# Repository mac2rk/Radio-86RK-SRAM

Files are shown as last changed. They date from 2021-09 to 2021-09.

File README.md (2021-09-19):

# Radio-86RK SRAM
The 2012 remake of the 1986 DIY 8-bit computer

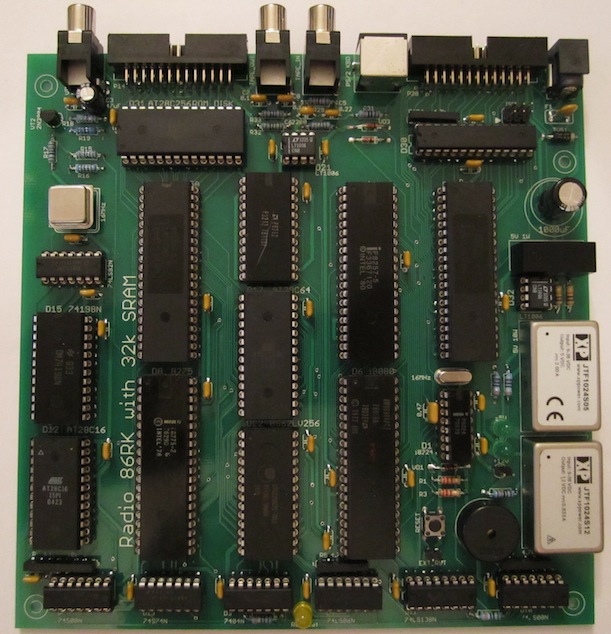
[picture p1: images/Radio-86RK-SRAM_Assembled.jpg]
Radio 86RK SRAM


## Contents
* [Introduction](#introduction)
* [Specifications](#specifications)
* [Hardware documentation](#hardware-documentation)
  * [Schematic and PCB Layout](#schematic-and-pcb-layout)
  * [Connectors](#connectors)
  * [Bill of Materials](#bill-of-materials)
  * [Memory Map](#memory-map)
* [Firmware documentation](#firmware-documentation)
  * [Monitor](#monitor)
  * [PS/2 adapter](#ps2-adapter)
* [Known Issues](#known-issues)

## Introduction
This project is a 2012 remake of [Radio-86RK](https://en.wikipedia.org/wiki/Radio-86RK), a DIY 8-bit computer the original design for which was published in 1986 by the Soviet *Radio* ham and DIY electronics magazine (hence the "Radio" and "86" in the name).

The original 1986 design targeted an enthusiast building it from scratch and was notable for its relative simplicity. Like most home computers of the era, it uses TV for video output and a cassette tape for program storage. Unlike most home computers, there is no color and no bitmapped graphics. You can get a feel of it via @begoon's excellent online [emulator](https://rk86.ru/) (the emulator's source code is [available on GitHub](https://github.com/begoon/rk86-js)).

The principal motivation behind this project was to replace the obsolete 1-bit DRAM memory and its supporting logic (address multiplexers, etc.) with a single 32KiB static RAM chip. A number of other changes has been made - see the [schematic](Eagle/Radio-86RK-SRAM-Schematic.pdf) for details. The project was initially [published](http://radio86rk.pbworks.com) around 2012 and since then has been built by a number of people, with one build even landing at the [Center for Computing History](http://www.computinghistory.org.uk/det/32376/Radio-86RK-(Russia)/) in Cambridge, thanks to @begoon. Also, this project seems to have inspired other designs, particularly @skiselev's [Radio-86RK](https://github.com/skiselev/radio-86rk) and [Радио-86РК-SRAM-128K](http://www.nedopc.org/forum/viewtopic.php?t=10660&start=0) by @shaos. 

## Specifications
  * CPU: Intel i8080 @ 2MHz
  * Memory: 32KiB RAM, 8 KiB ROM, optional 32KiB ROM cartridge (built-in or external)
  * Display: 64x25 alphanumeric monochrome (50Hz composite video output suitable for TV)
  * Keyboard: Proprietary 66-key (parallel interface) or any standard PS/2 (with built-in adapter)
  * Sound: 1-bit digital
  * I/O: Cassette tape recorder (use [mac2rk](https://github.com/mac2rk/mac2rk) to emulate tape recorder with a sound card)
  * Expansion: optional parallel port (required for ROM cartridges) 
  * Software: 2KiB ROM monitor; additional software can be loaded from a ROM cartridge or tape
  * Form factor: Mini-ITX (170x170 mm, 6.7x6.7 inch)
  * Power supply: 18-36VDC @ approx. 5W via barrel connector

## Hardware documentation

### Schematic and PCB Layout
[Schematic](Eagle/Radio-86RK-SRAM-Schematic.pdf)
[PCB Layout](Eagle/Radio-86RK-SRAM-Silk.pdf)

The computer is built around an Intel i8080 CPU (D6 on the schematic) with i8224 clock generator (D1). RAM and ROM are implemented with 62256 SRAM (D22) and 28C64 EEPROM (D17), respectively. Video subsystem includes an i8275 CRT controller (D8), i8257 DMA controller (D2) with address latch (D7), 28C16 font EEPROM (D12) and a parallel-in, serial-out shift register (D15). Two i8255 Programmable Peripheral Interfaces (PPIs) provide I/O connectivity. One PPI (D20) interfaces a cassete tape recorder and the parallel keyboard; a PS/2 keyboard can be connected via an onboard adapter (D30). The second PPI (D14) implements the expansion port, which can be used, among other things, to connect ROM cartridges. A 28C256 ROM cartridge can be either installed onboard (D30) or connected via a 26-way expansion header. The onboard power supply with power sequencing is built with three DC/DC converter modules (D33..D35) and an opamp (D32).

### Connectors
[Connectors](docs/Connectors.md)

### Bill of Materials
[Bill of Materials](docs/BOM.md)

### Memory Map
[Memory Map](docs/Memory_map.md)

## Firmware Documentation

### Monitor

[Monitor commands and subroutines](docs/Monitor.md)

### PS/2 adapter
The PS/2 to parallel keyboard adapter based on an ATmega48/88/168/328 MCU was developed and [published](https://zx-pk.ru/threads/9294-orion-128-kontroller-ps-2-klaviatury.html) by Kamil Karimov (caro). The source code for the adapter is not available, but the binary is known to work. Note that this adapter requires that the keyboard support Scan Code Set 3. Most do, but some (e.g. Logitech K100) don't and will not work properly with the adapter.

There are two separate versions of the compiled binary: one for ATmega48/88 and one for ATmega168/328. When programming the ATmega, all fuses except CKDIV8 should be left in their default states. CKDIV8 should be left unprogrammed. (CKDIV8 is programmed by default, which clocks the ATmega at 1MHz. With this clock, only Caps Lock (= Rus/Lat) and Print Screen (= Reset) will work normally. Other keys will not work at all or will work partially or intermittently.)

## Known Issues

* Top silkscreen: R109, which sets the current for the "+12V" LED, has a wrong value. Instead oof 330 ohm, it should be between 1kOhm and 1.5kOhm
* PS/2 adapter requires that the keyboard support Scan Code Set 3. Most do, but some (e.g. Logitech K100) don't and do not work properly with the adapter.

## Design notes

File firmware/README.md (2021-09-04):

# Radio-86RK SRAM firmware

radio86rk-monitor.bin - Monitor (28C64)
radio86rk-font.bin    - Font    (28C16)

## PS/2 Keyboard Adapter for Radio-86RK and similar computers with ATMega48(/88/168)

orion_kb_m48.hex - for ATmega48/88
orion_kb_m168.hex - for ATmega168/328

### PS/2 Keyboard Layouts

PS/2 adapter firmware implements two alternative keyboard layouts for convenience when working with both Latin and Cyrillic, which use different layouts on RK86 from compared to PC. With two layouts, you will see on the screen what is on the key.

Scroll Lock key will switch between two layouts. Scroll Lock indicator will show what layout is active. What Scroll Lock is off, the layout is Latin (QWERTY), when on - Cyrillic.

### Radio-86RK matrix layout

 A   | D7 | D6 | D5 | D4 | D3 | D2 | D1 | D0
 --- | ---- | ---- | ---- | ---- | ---- | ---- | ---- | ---
 A7 | SP | ^  | ]  | \  | [  | Z  | Y  | X
 A6 | W  | V  | U  | T  | S  | R  | Q  | P
 A5 | O  | N  | M  | L  | K  | J  | I  | H
 A4 | G  | F  | E  | D  | C  | B  | A  | @
 A3 | /  | .  | =  | ,  | ;  | :  | 9  | 8
 A2 | 7  | 6  | 5  | 4  | 3  | 2  | 1  | 0
 A1 | v  | -> |  ^ | <- | BS | CR | LF | TAB
 A0 | F5 | F4 | F3 | F2 | F1 | ESC | CLR | ^\

### Programming ATMega48 with PS/2 adapter firmware

The default Fuse and Lock bits for an ATmega48 are as follows:

Lock(&Fuse) | Fuse(Low)  | Fuse(High)    | Fuse(Ext)
------------ | ------------ | --------------- | ------------------
[v] LB1     | [ ] CKSEL0 | [v] BODLEVEL0 | [v] SELFPRGEN
[v] LB2     | [v] CKSEL1 | [v] BODLEVEL1 | [v] -
[v] BLB01   | [ ] CKSEL2 | [v] BODLEVEL2 | [v] -
[v] BLB10   | [ ] CKSEL3 | [v] EESAVE    | [v] -
[v] BLB11   | [ ] SUT0   | [v] WDTON     | [v] -
[v] BLB12   | [v] SUT1   | [ ] SPIEN     | [v] -
[v] -       | [v] CKOUT  | [v] DWEN      | [v] -
[v] -       | [ ] CKDIV8 | [v] RSTDISBL  | [v] -

You need to change:
1) Fuse(Low)/CKDIV8
2) Fuse(High)/BODLEVEL0,1

The result should look like:

Lock(&Fuse) | Fuse(Low)  | Fuse(High)    | Fuse(Ext)
------------ | ------------ | --------------- | ------------------
[v] LB1     | [ ] CKSEL0 | [ ] BODLEVEL0 | [v] SELFPRGEN
[v] LB2     | [v] CKSEL1 | [ ] BODLEVEL1 | [v] -
[v] BLB01   | [ ] CKSEL2 | [v] BODLEVEL2 | [v] -
[v] BLB10   | [ ] CKSEL3 | [v] EESAVE    | [v] -
[v] BLB11   | [ ] SUT0   | [v] WDTON     | [v] -
[v] BLB12   | [v] SUT1   | [ ] SPIEN     | [v] -
[v] -       | [v] CKOUT  | [v] DWEN      | [v] -
[v] -       | [V] CKDIV8 | [v] RSTDISBL  | [v] -

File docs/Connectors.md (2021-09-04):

# Radio-86RK SRAM Connectors
## VIDEO_OUT - Composite Video (RCA connector)

Pin | Description     
--- | ---------------
Tip (the inner contact) | Output: Composite Video
Ring / Sleeve |	Power: GND

## P14 - Expansion Port Connector (26-way box header)
Do not use if the internal ROM cartridge (D31) is installed.

Pin | Description | Pin | Description
--- | ----------- | --- | ----------------
1   | I/O: PC0 | 2   | I/O: PA0
3   | I/O: PC1 | 4   | I/O: PA1
5   | I/O: PC2 | 6   | I/O: PA2
7   | I/O: PC3 | 8   | I/O: PA3
9   | I/O: PC4 | 10  | I/O: PA4
11  | I/O: PC5 | 12  | I/O: PA5
13  | I/O: PC6 | 14  | I/O: PA6
15  | I/O: PC7 | 16  | I/O: PA7
17  | I/O: PB7 | 18  | I/O: PB0
19  | I/O: PB6 | 20  | I/O: PB1
21  | I/O: PB5 | 22  | I/O: PB2
23  | I/O: PB4 | 24  | I/O: PB3
25  | Power: +5V  | 26  | Power: GND

## TAPE_OUT - Tape Recorder Output (RCA connector)

Pin | Description     
--- | ---------------
Tip (the inner contact) | Output: Tape Recorder
Ring / Sleeve |	Power: GND

## TAPE_IN - Tape Recorder Input (RCA connector)

Pin | Description     
--- | ---------------
Tip (the inner contact) | Input: Tape Recorder
Ring / Sleeve |	Power: GND

## PS/2_KBD - PS/2 Keyboard (6-way Mini DIN)

Pin | Description     
--- | ---------------
1   | Input/Output: Data
2   |	Not connected
3   |	Power: GND
4   |	Power: +5V
5   |	Input/Output: Clock
6   |	Not connected

## P20 - Parallel Keyboard Connector (26-way box header)
Do not use if PS/2 adapter (D30) is installed.

Pin | Description | Pin | Description
--- | ----------- | --- | ----------------
1   | I/O: PC0 | 2   | I/O: PA0
3   | I/O: PC1 | 4   | I/O: PA1
5   | I/O: PC2 | 6   | I/O: PA2
7   | I/O: PC3 | 8   | I/O: PA3
9   | I/O: PC4 | 10  | I/O: PA4
11  | I/O: PC5 | 12  | I/O: PA5
13  | I/O: PC6 | 14  | I/O: PA6
15  | I/O: PC7 | 16  | I/O: PA7
17  | I/O: PB7 | 18  | I/O: PB0
19  | I/O: PB6 | 20  | I/O: PB1
21  | I/O: PB5 | 22  | I/O: PB2
23  | I/O: PB4 | 24  | I/O: PB3
25  | Power: +5V  | 26  | Power: GND

## ISP - In-System Programming for PS/2 Adapter

Pin | Description     
--- | ---------------
1   | Output: Data
2   |	Power: +5V
3   |	Input: Clock
4   |	Input: Data
5   |	Input: Reset (active low)
6   |	Power: GND

## 24V_IN - Power (18..36VDC @ 5W)

Pin | Description     
--- | ---------------
Tip (the inner contact) | Power: 18..36V (positive terminal)
Barrel / Sleeve         |	Power: GND (negative terminal)

## EXT_RST - Reset

Pin | Description     
--- | ---------------
1   | Input: Reset (active low)
2   |	Power: GND

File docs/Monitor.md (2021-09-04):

# Radio-86RK SRAM Monitor
(based on @skiselev's work)

## Monitor Commands
* **D\<Start_Address\>,\<End_Address\>** - Display memory content in hexadecimal
* **L\<Start_Address\>,\<End_Address\>** - Display memory content in ASCII
* **F\<Start_Address\>,\<End_Address\>,\<Value\>** - Fill memory with the specified value
* **M\<Address\>** - Modify memory content
* **T\<Start_Address\>,\<End_Address\>,\<Destination_Start_Address\>** - Copy memory block to destination
* **C\<Start_Address\>,\<End_Address\>,\<Destination_Start_Address\>** - Compare memory block with destination
* **S\<Start_Address\>,\<End_Address\>,\<Value\>** - Search memory for a value
* **R\<ROM_Start_Address\>,\<ROM_End_Address\>,\<Destination_Start_Address\>** - Read from the ROM cartridge
* **G\<Start_Address\>\[,End_Address\]** - Run code, optionally stop at the specified address
* **X** - Display and modify registers
* **O\<Start_Address\>,\<End_Address\>\[,Speed\]** - Write memory to cassette. Default speed is 1Dh / 1200 bps
* **I\[Offset\]\[,Speed\]** - Read data from to cassette memory at specified offset

## Monitor Subroutines:
* 0F803h - Keyboard input
  * Input: None
  * Output: A - character code read from keyboard
* 0F806h - Cassette input
  * Input: A=0FFh - with sync; A=08h - no sync
  * Output: A - data read from cassette
* 0F809h - Print character to screen
  * Input: C - character to print
* 0F80Ch - Cassette output
  * Input: C - data to write
* 0F812h - Query keyboard
  * Output: A=00h - key not pressed; A=0FFh - key pressed
* 0F815h - Print to screen in hex
  * Input: A - data to print
* 0F818h - Print string
  * Input: HL - string address
* 0F81Bh - Get key
  * Output: A=0FFh - key not pressed; A=0FEh - Rus/Lat; otherwise A - key code
* 0F81Eh - Get cursor position
  * Output: H - row, L - column
* 0F821h - Read character from screen at current cursor position
  * Output: A - char read from screen
* 0F824h - Read from cassette
  * Input: HL - offset of memory buffer to store data to
  * Output: HL - start; DE - end; BC - checksum

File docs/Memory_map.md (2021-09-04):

# Radio-86RK SRAM Memory Map
* 0000h - 7FFFh - SRAM
  * 7600h - 7FFFh - Display buffer and monitor variables
* 8000h - 8FFFh - 8255A PPI (D20 - Keyboard and Cassette Tape Recorder)
  * 8000h - Channel A data
  * 8001h - Channel B data
  * 8002h - Channel C data
  * 8003h - Control word
* 9000h - 9FFFh - Unused
* 0A000h - 0AFFFh - 8255A PPI (D14 - Expansion Port)
  * 0A000h - Channel A data
  * 0A001h - Channel B data
  * 0A002h - Channel C data
  * 0A003h - Control word
* 0B000h - 0BFFFh - Unused
* 0C000h - 0CFFFh - 8275 CRT Controller
* 0D000h - 0DFFFh - Unused
* 0E000h - 0EFFFh - 8257 DMA Controller (write only)
* 0E000h - 0FFFFh - Monitor ROM (read only)

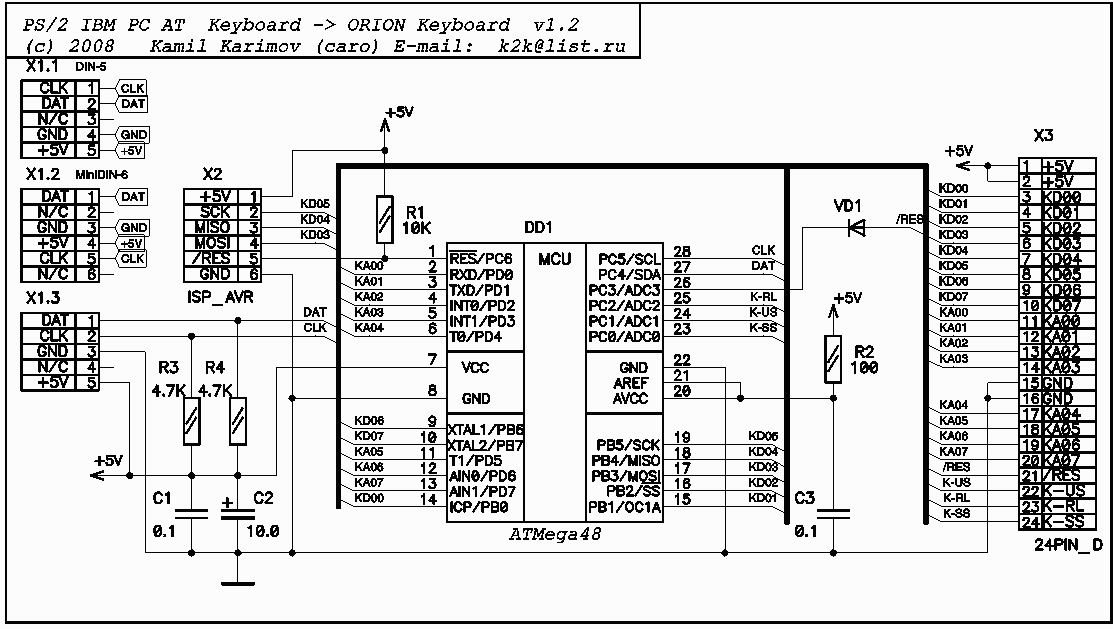
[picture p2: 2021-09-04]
firmware/adapter schematic.png

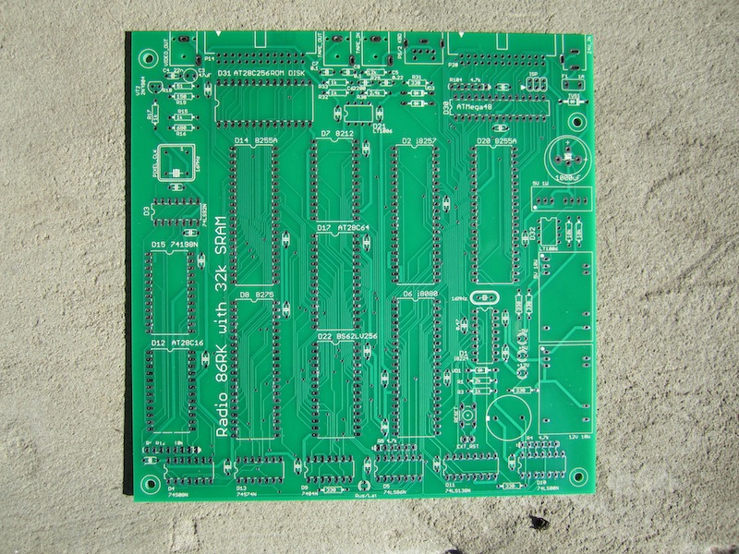
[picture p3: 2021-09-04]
images/Radio-86RK-SRAM_Bare_Board.jpg

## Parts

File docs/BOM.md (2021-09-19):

# Radio-86RK SRAM Bill of Materials

Name    | Type      | Quantity  | Notes
------- | --------- | --------- | ------
D1      | i8224     | 1         | eBay
D2      | i8257     | 1         | eBay 	
D3      | 74LS92N   | 1 	    | 
D4      | 74LS08N   | 1 	    |
D5      | 74LS86N   | 1 	    |
D6      | i8080     | 1 	    | eBay
D7      | i8212     | 1         | eBay
D8      | i8275     | 1         | eBay
D9      | 74LS04N   | 1         | 	 
D10     | 74LS00N   | 1         | 	 
D11     | 74LS138N  | 1         | 	 
D12     | AT28C16   | 1         | 	 
D13     | 74S74N    | 1 	    | 
D14, D20| i8255(A)  | 2         | eBay	 
D15     | 74198N    | 1 	    | eBay
D17     | AT28C64   | 1         | eBay
D21, D32| LT1006    | 2         |
D22     | BS62LV256, UT62256CPC, etc. | 1 | 	 
D30     | ATMega48/88/168/328 | 1 | 	 
D31     | AT28C256  | 1         | 	 
D33     | XP POWER IW2405SA | 1 | or similar
D34     | XP POWER JTF1024S05 | 1 | or similar
D35     | XP POWER JTF1024S12 | 1 | or similar
n/a | Socket DIL08 300mil | 2 | optional but recommended
n/a | Socket DIL14 300mil | 6 | optional but recommended
n/a | Socket DIL16 300mil | 2 | optional but recommended
n/a | Socket DIL24 600mil | 3 | optional but recommended
n/a | Socket DIL28 300mil | 1 | optional but recommended
n/a | Socket DIL28 600mil | 3 | optional but recommended
n/a | Socket DIL40 600mil | 5 | optional but recommended
P14, P20| 2.54mm 2x13 box header, right angle | 2 | 	 
TAPE_IN,TAPE_OUT,VIDEO_OUT | LUMBERG WBTOR RCA connector | 2 | obsolete
DIN1    | Mini-DIN 6-way    | 1 |
EXT_RST | 2.54mm 1x2 header | 1 | 	 
ISP     | 2.54mm 2x3 header | 1 | 	 
24V_IN  | 5.5mm x 2.1мм or 5.5mm x 2.5mm barrel power connector | 1 | 	 
R1  | Resistor 2kOhm 1/4W | 1 | 	 
R3, R15, R17, R32, R33 | Resistor 1kOhm 1/4W |	5 | 	 
R4, R5, R104 | Resistor array 5x4.7kOhm | 3 | bus topology	 
R6-R12  | Resistor array 7x10kOhm |	1 | bus topology
R16     | Resistor 680 Ohm 1/4W | 1 |
R18     | Resistor 51 Ohm 1/4W | 1 | 	 
R19     | Resistor 150 Ohm  1/4W | 1 | 	 
R29     | Resistor 12 kOhm 1/4W | 1 | 	 
R30     | Resistor 2.4 kOhm 1/4W | 1 | 	 
R31, R101, R103, R110, R111 | Resistor 330 Ohm 1/4W | 6 | 	 
R109    | Resistor 1.1 kOhm 1/4W | 1 |  	  	 
R107, R108 | Resistor 10 kOhm 1/4W | 2 | 	 
C2 	    | Capacitor ceramic 0.47uF LS=5mm |	1 | 	 
C3 	    | Capacitor electrolytic 22..47uF LS=2.5mm | 1 | 	 
C4 	    | Capacitor ceramic 22nF LS=5mm | 1 | 	 
C5 	    | Capacitor ceramic 0.22uF LS=5mm | 1 | 	 
C6 	    | Capacitor ceramic 2.2nF LS=5mm  | 1 |  	 
C7-C12, C17-C25, C101-C114 | Capacitor ceramic 0.1uF LS=5mm | 29 | 	 
C115(116) |	Capacitor electrolytic 330..1000uF LS=5 or 7.5mm | 1 | 	 
VD1, VD3, VD101 | 1N4148 | 3 | 	 
VT2     | 2N3904 | 1 | 	 
+5V, +12V, -5V, LED | LEDs 3mm | 4 | 	 
TVS1    | TVS 24V | 1 | 	 
F1      | PTC fuse 0.5A LS=5mm  | 1 | 	 
H1      | Piezo speaker LS=10mm | 1 | 	 
Z1      | Crystal 18.432Mhz, HC-49 | 1 | 	 
PIXEL_CLK |	Oscillator TTL/HCMOS 16Mhz, DIL8 | 1 | 	 
RESET   | TACT momentary button | 1 | 	 

Comments:
* Logic can be TTL (e.g. 74198N) or from LS/ALS/HCT familes
* Opamp (D21) can be any single opamp rated for +/-5V operation
* Opamp (D32) can be any single opamp rated for 12..24V single supply operation
* For D30, any of ATmega48/88/168/328 can be used, but note that 48/88 have different firmware from 168/328
* DC/DC moduled can be replaced with equivalents, provided that the @Enable pin is connected correctly.
* Resistor arrays can be anything with bus topology (e.g. one common pin) with the value between 4..20kOhm. Bourns 4308R-101 and 4306R-101 are sutbale examples. 
* R109's value on the schetic and silk screen is wrong - it should be 1 to 1.5kOhm.
* LUMBERG WBTOR RCA connectors are obsolete and no longer manufactured. Consider using offboard connectors or amending the board design for the connectors that are available.

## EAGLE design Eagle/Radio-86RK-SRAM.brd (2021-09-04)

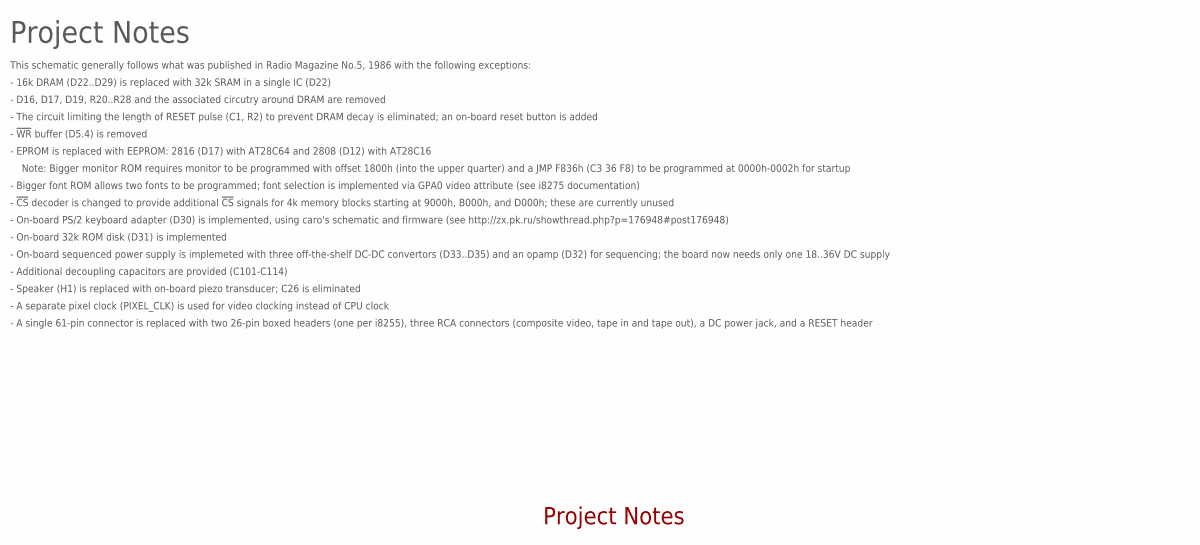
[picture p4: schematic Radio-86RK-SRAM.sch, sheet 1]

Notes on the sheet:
Project Notes
This schematic generally follows what was published in Radio Magazine No.5, 1986 with the following exceptions:
- 16k DRAM (D22..D29) is replaced with 32k SRAM in a single IC (D22)
- D16, D17, D19, R20..R28 and the associated circutry around DRAM are removed
- EPROM is replaced with EEPROM: 2816 (D17) with AT28C64 and 2808 (D12) with AT28C16
- !WR! buffer (D5.4) is removed
- !CS! decoder is changed to provide additional !CS! signals for 4k memory blocks starting at 9000h, B000h, and D000h; these are currently unused
Note: Bigger monitor ROM requires monitor to be programmed with offset 1800h (into the upper quarter) and a JMP F836h (C3 36 F8) to be programmed at 0000h-0002h for startup
- Bigger font ROM allows two fonts to be programmed; font selection is implemented via GPA0 video attribute (see i8275 documentation)
- On-board sequenced power supply is implemeted with three off-the-shelf DC-DC convertors (D33..D35) and an opamp (D32) for sequencing; the board now needs only one 18..36V DC supply
- Additional decoupling capacitors are provided (C101-C114)
- On-board PS/2 keyboard adapter (D30) is implemented, using caro's schematic and firmware (see http://zx.pk.ru/showthread.php?p=176948#post176948)
- On-board 32k ROM disk (D31) is implemented
- Speaker (H1) is replaced with on-board piezo transducer; C26 is eliminated
- A separate pixel clock (PIXEL_CLK) is used for video clocking instead of CPU clock
- A single 61-pin connector is replaced with two 26-pin boxed headers (one per i8255), three RCA connectors (composite video, tape in and tape out), a DC power jack, and a RESET header
- The circuit limiting the length of RESET pulse (C1, R2) to prevent DRAM decay is eliminated; an on-board reset button is added

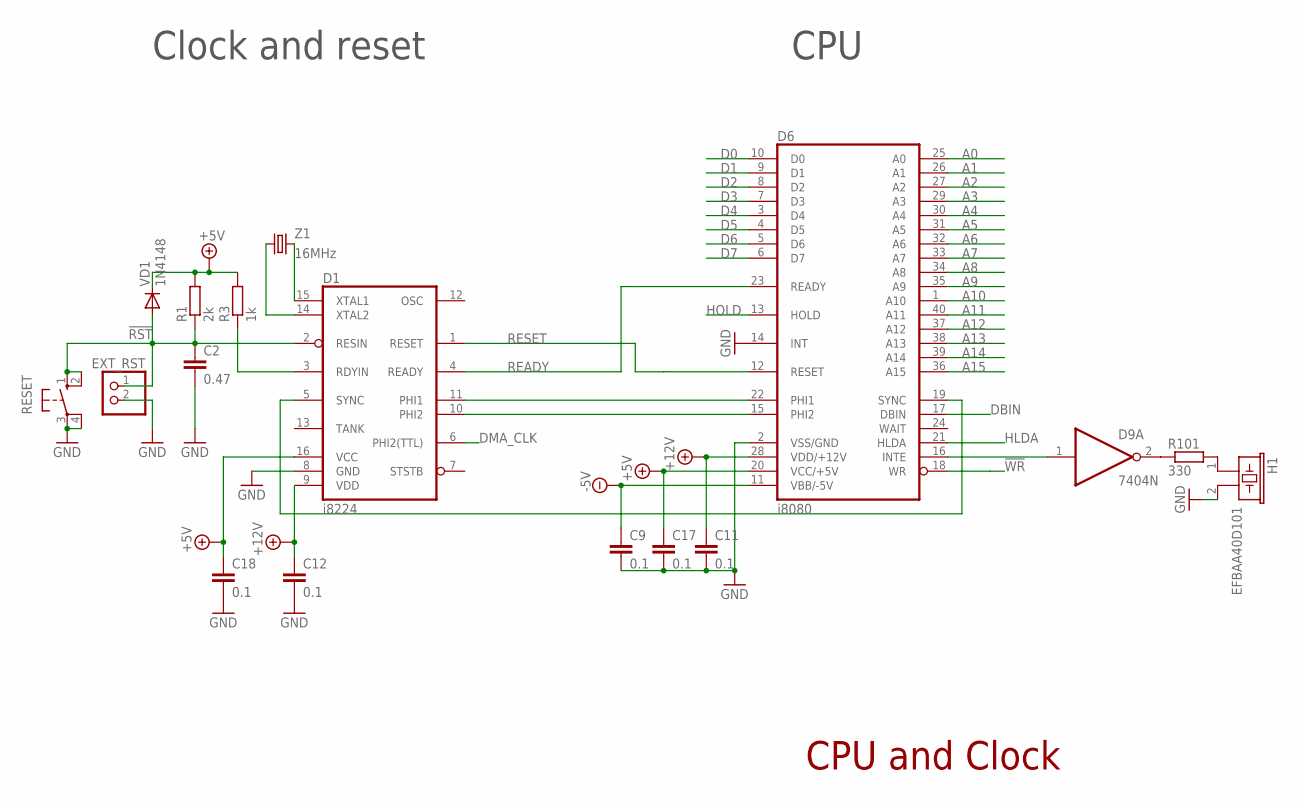
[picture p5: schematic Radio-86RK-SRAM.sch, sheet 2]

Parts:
C2: 0.47; C050-024X044
C9, C11, C12, C17, C18: 0.1; C050-024X044
D1: i8224; DIL16
D6: i8080; DIL40
D9: 7404N; DIL14
EXT_RST: PINHD-1X2; 1X02
H1: EFBAA40D101
R1: 2k; 0207/10
R3: 1k; 0207/10
R101: 330; 0207/10
RESET: 10-XX; B3F-10XX
VD1: 1N4148; DO35-10
Z1: 16MHz; HC49U-V

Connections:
!RST: C2.1, D1.2 (RESIN), EXT_RST.1, R1.1, RESET.1 (S), RESET.2 (S1), VD1.A; also elsewhere on the board
!WR: D6.18 (WR); also elsewhere on the board
+5V: C17.1, C18.1, D1.16 (VCC), D6.20 (VCC/+5V), R1.2, R3.2, VD1.C; also elsewhere on the board
+12V: C11.1, C12.1, D1.9 (VDD), D6.28 (VDD/+12V); also elsewhere on the board
-5V: C9.1, D6.11 (VBB/-5V); also elsewhere on the board
A0: D6.25 (A0); also elsewhere on the board
A1: D6.26 (A1); also elsewhere on the board
A2: D6.27 (A2); also elsewhere on the board
A3: D6.29 (A3); also elsewhere on the board
A4: D6.30 (A4); also elsewhere on the board
A5: D6.31 (A5); also elsewhere on the board
A6: D6.32 (A6); also elsewhere on the board
A7: D6.33 (A7); also elsewhere on the board
A8: D6.34 (A8); also elsewhere on the board
A9: D6.35 (A9); also elsewhere on the board
A10: D6.1 (A10); also elsewhere on the board
A11: D6.40 (A11); also elsewhere on the board
A12: D6.37 (A12); also elsewhere on the board
A13: D6.38 (A13); also elsewhere on the board
A14: D6.39 (A14); also elsewhere on the board
A15: D6.36 (A15); also elsewhere on the board
D0: D6.10 (D0); also elsewhere on the board
D1: D6.9 (D1); also elsewhere on the board
D2: D6.8 (D2); also elsewhere on the board
D3: D6.7 (D3); also elsewhere on the board
D4: D6.3 (D4); also elsewhere on the board
D5: D6.4 (D5); also elsewhere on the board
D6: D6.5 (D6); also elsewhere on the board
D7: D6.6 (D7); also elsewhere on the board
DBIN: D6.17 (DBIN); also elsewhere on the board
DMA_CLK: D1.6 (PHI2(TTL)); also elsewhere on the board
GND: C2.2, C9.2, C11.2, C12.2, C17.2, C18.2, D1.8 (GND), D6.2 (VSS/GND), D6.14 (INT), EXT_RST.2, H1.2, RESET.3, RESET.4 (P1); also elsewhere on the board
HLDA: D6.21 (HLDA); also elsewhere on the board
HOLD: D6.13 (HOLD); also elsewhere on the board
unnamed: D1.11 (PHI1), D6.22 (PHI1)
unnamed: D1.10 (PHI2), D6.15 (PHI2)
unnamed: D1.15 (XTAL1), Z1.2
unnamed: D1.14 (XTAL2), Z1.1
unnamed: D1.5 (SYNC), D6.19 (SYNC)
unnamed: D1.3 (RDYIN), R3.1
unnamed: D6.16 (INTE), D9.1 (I)
unnamed: H1.1, R101.2
unnamed: D9.2 (O), R101.1
READY: D1.4 (READY), D6.23 (READY); also elsewhere on the board
RESET: D1.1 (RESET), D6.12 (RESET); also elsewhere on the board

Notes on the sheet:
CPU and Clock
Clock and reset
CPU

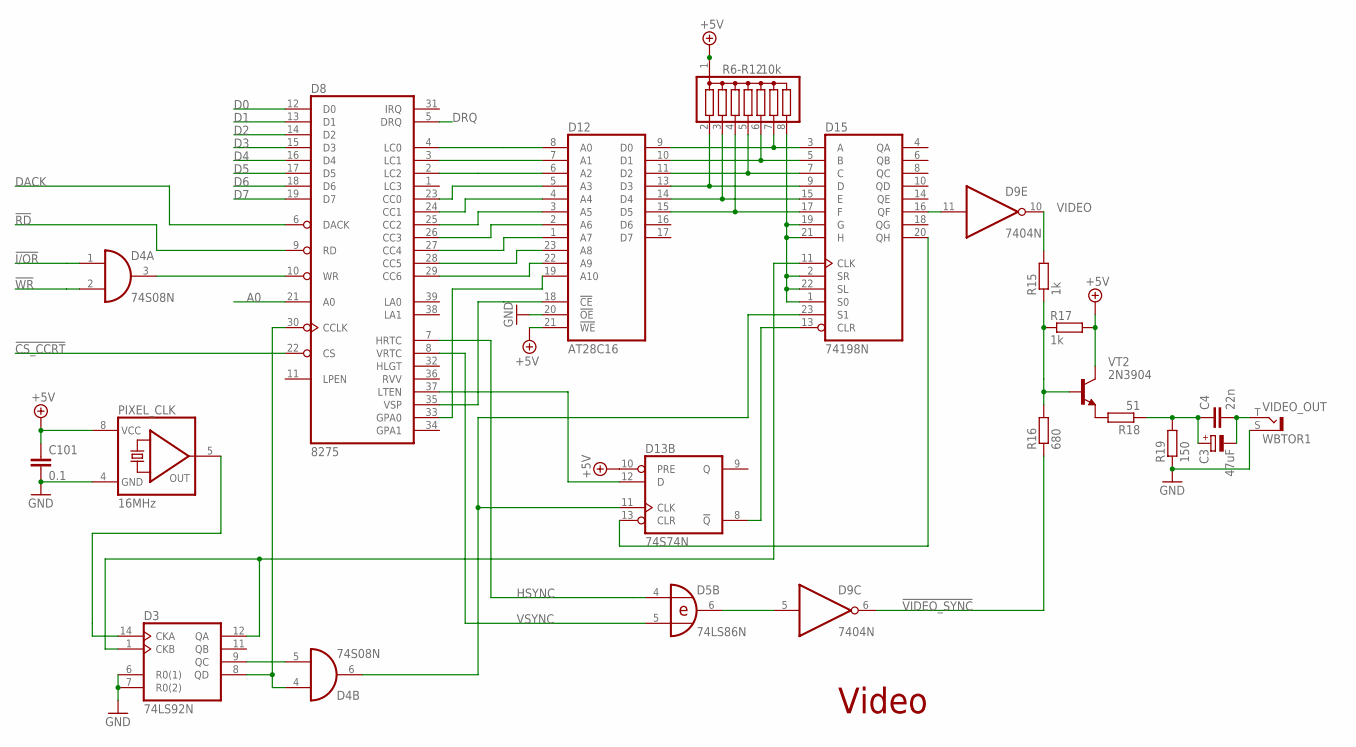
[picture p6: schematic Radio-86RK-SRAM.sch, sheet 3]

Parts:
C3: 47uF; E2,5-5
C4: 22n; C050-024X044
C101: 0.1; C050-024X044
D3: 74LS92N; DIL14
D4: 74S08N; DIL14
D5: 74LS86N; DIL14
D8: 8275; DIL40
D9: 7404N; DIL14
D12: AT28C16; DIL24
D13: 74S74N; DIL14
D15: 74198N; DIL24-6
PIXEL_CLK: 16MHz; DIL08S
R6-R12: 10k; SIL8
R15, R17: 1k; 0207/10
R16: 680; 0207/10
R18: 51; 0207/10
R19: 150; 0207/10
VIDEO_OUT: WBTOR1; MPN WBTOR 1 BLACK
VT2: 2N3904; TO92

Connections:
!CS_CCRT: D8.22 (CS); also elsewhere on the board
!I/OR: D4.1 (I0); also elsewhere on the board
!RD: D8.9 (RD); also elsewhere on the board
!VIDEO: D9.11 (I), D15.16 (QF)
!VIDEO_SYNC: D9.6 (O), R16.1
!WR: D4.2 (I1); also elsewhere on the board
+5V: C101.1, D12.21 (!WE), D13.10 (PRE), PIXEL_CLK.8 (VCC), R6-R12.1, R17.2, VT2.1 (C); also elsewhere on the board
A0: D8.21 (A0); also elsewhere on the board
COMPOSITE_VIDEO: C3.-, C4.2, VIDEO_OUT.T
D0: D8.12 (D0); also elsewhere on the board
D1: D8.13 (D1); also elsewhere on the board
D2: D8.14 (D2); also elsewhere on the board
D3: D8.15 (D3); also elsewhere on the board
D4: D8.16 (D4); also elsewhere on the board
D5: D8.17 (D5); also elsewhere on the board
D6: D8.18 (D6); also elsewhere on the board
D7: D8.19 (D7); also elsewhere on the board
DACK: D8.6 (DACK); also elsewhere on the board
DRQ: D8.5 (DRQ); also elsewhere on the board
GND: C101.2, D3.6 (R0(1)), D3.7 (R0(2)), D12.20 (!OE), PIXEL_CLK.4 (GND), R19.1, VIDEO_OUT.S; also elsewhere on the board
HSYNC: D5.4 (I0), D8.7 (HRTC)
unnamed: D3.14 (CKA), PIXEL_CLK.5 (OUT)
unnamed: D3.1 (CKB), D3.12 (QA), D15.11 (CLK)
unnamed: D4.3 (O), D8.10 (WR)
unnamed: D3.9 (QC), D4.5 (I1)
unnamed: D3.8 (QD), D4.4 (I0), D8.30 (CCLK)
unnamed: D8.23 (CC0), D12.5 (A3)
unnamed: D8.24 (CC1), D12.4 (A4)
unnamed: D8.25 (CC2), D12.3 (A5)
unnamed: D8.26 (CC3), D12.2 (A6)
unnamed: D8.27 (CC4), D12.1 (A7)
unnamed: D8.4 (LC0), D12.8 (A0)
unnamed: D8.3 (LC1), D12.7 (A1)
unnamed: D8.2 (LC2), D12.6 (A2)
unnamed: D8.35 (VSP), D12.18 (!CE)
unnamed: D12.9 (D0), D15.3 (A), R6-R12.7
unnamed: D8.28 (CC5), D12.23 (A8)
unnamed: D8.29 (CC6), D12.22 (A9)
unnamed: D12.10 (D1), D15.5 (B), R6-R12.6
unnamed: D12.11 (D2), D15.7 (C), R6-R12.5
unnamed: D12.13 (D3), D15.9 (D), R6-R12.2
unnamed: D12.14 (D4), D15.15 (E), R6-R12.3
unnamed: D12.15 (D5), D15.17 (F), R6-R12.4
unnamed: D13.13 (CLR), D15.20 (QH)
unnamed: D13.8 (!Q), D15.13 (CLR)
unnamed: D4.6 (O), D13.11 (CLK), D15.23 (S1)
unnamed: D8.37 (LTEN), D13.12 (D)
unnamed: R15.1, R16.2, R17.1, VT2.2 (B)
unnamed: D5.6 (O), D9.5 (I)
unnamed: R18.2, VT2.3 (E)
unnamed: C3.+, C4.1, R18.1, R19.2
unnamed: D8.33 (GPA0), D12.19 (A10)
unnamed: D15.1 (S0), D15.2 (SR), D15.19 (G), D15.21 (H), D15.22 (SL), R6-R12.8
VIDEO: D9.10 (O), R15.2
VSYNC: D5.5 (I1), D8.8 (VRTC)

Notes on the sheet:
Video

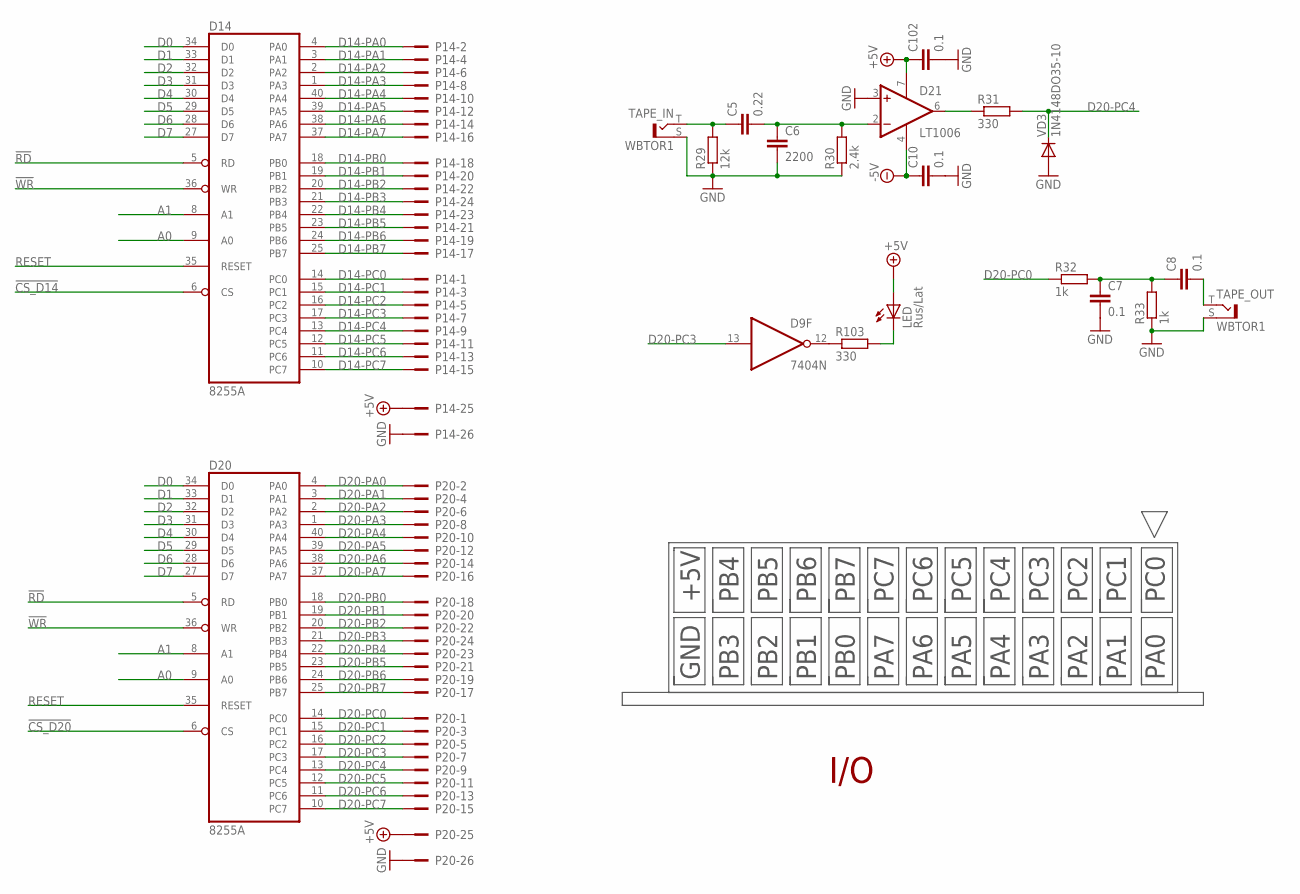
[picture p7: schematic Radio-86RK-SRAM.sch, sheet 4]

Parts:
C5: 0.22; C050-024X044
C6: 2200; C050-024X044
C7, C8, C10, C102: 0.1; C050-024X044
D9: 7404N; DIL14
D14, D20: 8255A; DIL40
D21: LT1006; DIL08
LED: Rus/Lat; LED3MM
P14, P20: 2526-5; PAK100/2500-5-26
R29: 12k; 0207/10
R30: 2.4k; 0207/10
R31, R103: 330; 0207/10
R32, R33: 1k; 0207/10
TAPE_IN: WBTOR1; MPN WBTOR 1 BLACK
TAPE_OUT: WBTOR1; MPN WBTOR 1 BLACK
VD3: 1N4148DO35-10; DO35-10

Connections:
!CS_D14: D14.6 (CS); also elsewhere on the board
!CS_D20: D20.6 (CS); also elsewhere on the board
!RD: D14.5 (RD), D20.5 (RD); also elsewhere on the board
!WR: D14.36 (WR), D20.36 (WR); also elsewhere on the board
+5V: C102.1, D21.7 (V+), LED.A, P14.25, P20.25; also elsewhere on the board
-5V: C10.1, D21.4 (V-); also elsewhere on the board
A0: D14.9 (A0), D20.9 (A0); also elsewhere on the board
A1: D14.8 (A1), D20.8 (A1); also elsewhere on the board
D0: D14.34 (D0), D20.34 (D0); also elsewhere on the board
D1: D14.33 (D1), D20.33 (D1); also elsewhere on the board
D2: D14.32 (D2), D20.32 (D2); also elsewhere on the board
D3: D14.31 (D3), D20.31 (D3); also elsewhere on the board
D4: D14.30 (D4), D20.30 (D4); also elsewhere on the board
D5: D14.29 (D5), D20.29 (D5); also elsewhere on the board
D6: D14.28 (D6), D20.28 (D6); also elsewhere on the board
D7: D14.27 (D7), D20.27 (D7); also elsewhere on the board
D14-PA0: D14.4 (PA0), P14.2; also elsewhere on the board
D14-PA1: D14.3 (PA1), P14.4; also elsewhere on the board
D14-PA2: D14.2 (PA2), P14.6; also elsewhere on the board
D14-PA3: D14.1 (PA3), P14.8; also elsewhere on the board
D14-PA4: D14.40 (PA4), P14.10; also elsewhere on the board
D14-PA5: D14.39 (PA5), P14.12; also elsewhere on the board
D14-PA6: D14.38 (PA6), P14.14; also elsewhere on the board
D14-PA7: D14.37 (PA7), P14.16; also elsewhere on the board
D14-PB0: D14.18 (PB0), P14.18; also elsewhere on the board
D14-PB1: D14.19 (PB1), P14.20; also elsewhere on the board
D14-PB2: D14.20 (PB2), P14.22; also elsewhere on the board
D14-PB3: D14.21 (PB3), P14.24; also elsewhere on the board
D14-PB4: D14.22 (PB4), P14.23; also elsewhere on the board
D14-PB5: D14.23 (PB5), P14.21; also elsewhere on the board
D14-PB6: D14.24 (PB6), P14.19; also elsewhere on the board
D14-PB7: D14.25 (PB7), P14.17; also elsewhere on the board
D14-PC0: D14.14 (PC0), P14.1; also elsewhere on the board
D14-PC1: D14.15 (PC1), P14.3; also elsewhere on the board
D14-PC2: D14.16 (PC2), P14.5; also elsewhere on the board
D14-PC3: D14.17 (PC3), P14.7; also elsewhere on the board
D14-PC4: D14.13 (PC4), P14.9; also elsewhere on the board
D14-PC5: D14.12 (PC5), P14.11; also elsewhere on the board
D14-PC6: D14.11 (PC6), P14.13; also elsewhere on the board
D14-PC7: D14.10 (PC7), P14.15; also elsewhere on the board
D20-PA0: D20.4 (PA0), P20.2; also elsewhere on the board
D20-PA1: D20.3 (PA1), P20.4; also elsewhere on the board
D20-PA2: D20.2 (PA2), P20.6; also elsewhere on the board
D20-PA3: D20.1 (PA3), P20.8; also elsewhere on the board
D20-PA4: D20.40 (PA4), P20.10; also elsewhere on the board
D20-PA5: D20.39 (PA5), P20.12; also elsewhere on the board
D20-PA6: D20.38 (PA6), P20.14; also elsewhere on the board
D20-PA7: D20.37 (PA7), P20.16; also elsewhere on the board
D20-PB0: D20.18 (PB0), P20.18; also elsewhere on the board
D20-PB1: D20.19 (PB1), P20.20; also elsewhere on the board
D20-PB2: D20.20 (PB2), P20.22; also elsewhere on the board
D20-PB3: D20.21 (PB3), P20.24; also elsewhere on the board
D20-PB4: D20.22 (PB4), P20.23; also elsewhere on the board
D20-PB5: D20.23 (PB5), P20.21; also elsewhere on the board
D20-PB6: D20.24 (PB6), P20.19; also elsewhere on the board
D20-PB7: D20.25 (PB7), P20.17; also elsewhere on the board
D20-PC0: D20.14 (PC0), P20.1, R32.1
D20-PC1: D20.15 (PC1), P20.3
D20-PC2: D20.16 (PC2), P20.5
D20-PC3: D9.13 (I), D20.17 (PC3), P20.7
D20-PC4: D20.13 (PC4), P20.9, R31.2, VD3.C
D20-PC5: D20.12 (PC5), P20.11; also elsewhere on the board
D20-PC6: D20.11 (PC6), P20.13; also elsewhere on the board
D20-PC7: D20.10 (PC7), P20.15; also elsewhere on the board
GND: C6.2, C7.2, C10.2, C102.2, D21.3 (+IN), P14.26, P20.26, R29.1, R30.1, R33.1, TAPE_IN.S, TAPE_OUT.S, VD3.A; also elsewhere on the board
unnamed: D9.12 (O), R103.1
unnamed: LED.K (C), R103.2
unnamed: C5.2, C6.1, D21.2 (-IN), R30.2
unnamed: C7.1, C8.1, R32.2, R33.2
unnamed: D21.6 (OUT), R31.1
unnamed: C5.1, R29.2, TAPE_IN.T
unnamed: C8.2, TAPE_OUT.T
RESET: D14.35 (RESET), D20.35 (RESET); also elsewhere on the board

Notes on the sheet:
I/O
GND
PB3
PB2
PB1
PB0
PA7
PA6
PA5
PA4
PA3
PA2
PA1
PA0
+5V
PB4
PB5
PB6
PB7
PC7
PC6
PC5
PC4
PC3
PC2
PC1
PC0

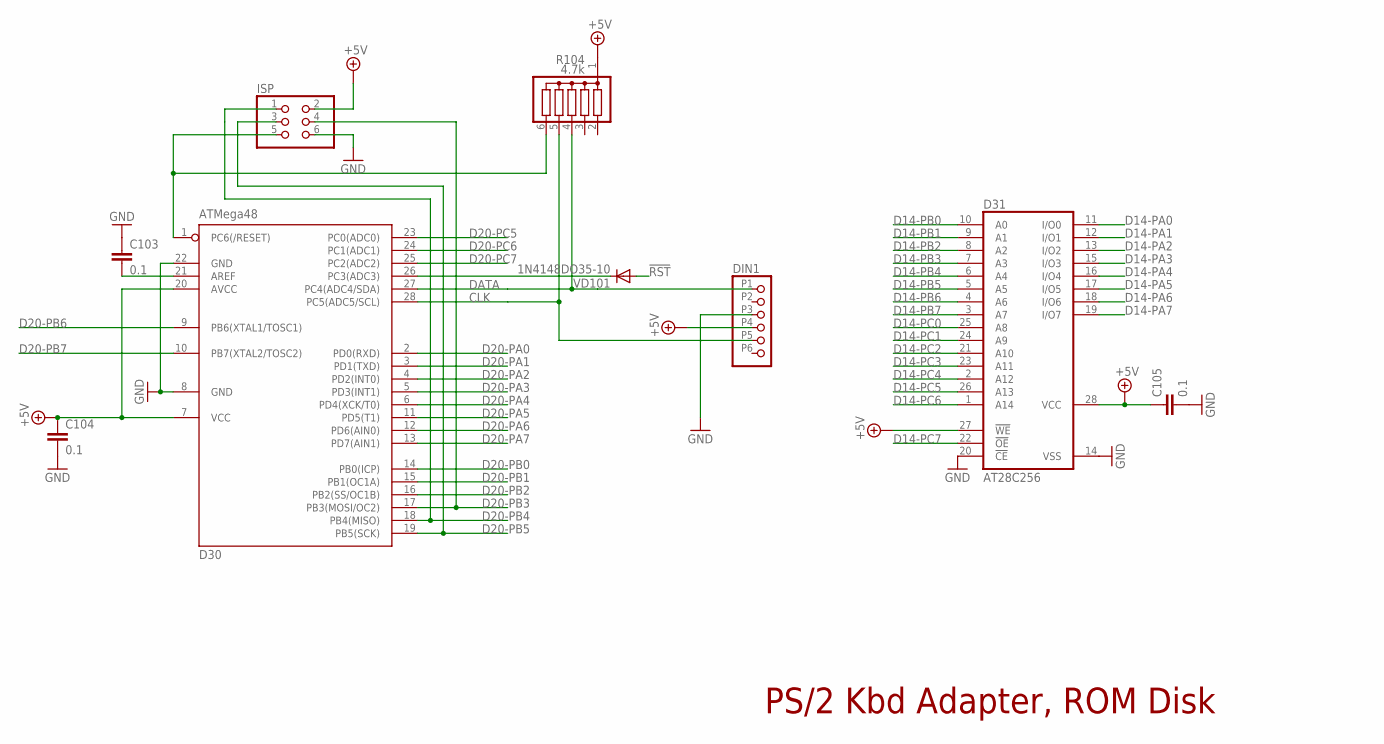
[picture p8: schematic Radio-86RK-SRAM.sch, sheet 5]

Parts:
C103, C104, C105: 0.1; C050-024X044
D30: ATMega48; DIL28-3
D31: AT28C256; DIL28-6
DIN1: TM0508A/6; MINI-DIN6
ISP: PINHD-2X3; 2X03
R104: 4.7k; SIL6
VD101: 1N4148DO35-10; DO35-10

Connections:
!RST: VD101.A; also elsewhere on the board
+5V: C104.1, C105.1, D30.7 (VCC), D30.20 (AVCC), D31.27 (!WE), D31.28 (VCC), DIN1.P4 (4), ISP.2, R104.1; also elsewhere on the board
CLK: D30.28 (PC5(ADC5/SCL)), DIN1.P5 (5), R104.5
D14-PA0: D31.11 (I/O0); also elsewhere on the board
D14-PA1: D31.12 (I/O1); also elsewhere on the board
D14-PA2: D31.13 (I/O2); also elsewhere on the board
D14-PA3: D31.15 (I/O3); also elsewhere on the board
D14-PA4: D31.16 (I/O4); also elsewhere on the board
D14-PA5: D31.17 (I/O5); also elsewhere on the board
D14-PA6: D31.18 (I/O6); also elsewhere on the board
D14-PA7: D31.19 (I/O7); also elsewhere on the board
D14-PB0: D31.10 (A0); also elsewhere on the board
D14-PB1: D31.9 (A1); also elsewhere on the board
D14-PB2: D31.8 (A2); also elsewhere on the board
D14-PB3: D31.7 (A3); also elsewhere on the board
D14-PB4: D31.6 (A4); also elsewhere on the board
D14-PB5: D31.5 (A5); also elsewhere on the board
D14-PB6: D31.4 (A6); also elsewhere on the board
D14-PB7: D31.3 (A7); also elsewhere on the board
D14-PC0: D31.25 (A8); also elsewhere on the board
D14-PC1: D31.24 (A9); also elsewhere on the board
D14-PC2: D31.21 (A10); also elsewhere on the board
D14-PC3: D31.23 (A11); also elsewhere on the board
D14-PC4: D31.2 (A12); also elsewhere on the board
D14-PC5: D31.26 (A13); also elsewhere on the board
D14-PC6: D31.1 (A14); also elsewhere on the board
D14-PC7: D31.22 (!OE); also elsewhere on the board
D20-PA0: D30.2 (PD0(RXD)); also elsewhere on the board
D20-PA1: D30.3 (PD1(TXD)); also elsewhere on the board
D20-PA2: D30.4 (PD2(INT0)); also elsewhere on the board
D20-PA3: D30.5 (PD3(INT1)); also elsewhere on the board
D20-PA4: D30.6 (PD4(XCK/T0)); also elsewhere on the board
D20-PA5: D30.11 (PD5(T1)); also elsewhere on the board
D20-PA6: D30.12 (PD6(AIN0)); also elsewhere on the board
D20-PA7: D30.13 (PD7(AIN1)); also elsewhere on the board
D20-PB0: D30.14 (PB0(ICP)); also elsewhere on the board
D20-PB1: D30.15 (PB1(OC1A)); also elsewhere on the board
D20-PB2: D30.16 (PB2(SS/OC1B)); also elsewhere on the board
D20-PB3: D30.17 (PB3(MOSI/OC2)), ISP.4; also elsewhere on the board
D20-PB4: D30.18 (PB4(MISO)), ISP.1; also elsewhere on the board
D20-PB5: D30.19 (PB5(SCK)), ISP.3; also elsewhere on the board
D20-PB6: D30.9 (PB6(XTAL1/TOSC1)); also elsewhere on the board
D20-PB7: D30.10 (PB7(XTAL2/TOSC2)); also elsewhere on the board
D20-PC5: D30.23 (PC0(ADC0)); also elsewhere on the board
D20-PC6: D30.24 (PC1(ADC1)); also elsewhere on the board
D20-PC7: D30.25 (PC2(ADC2)); also elsewhere on the board
DATA: D30.27 (PC4(ADC4/SDA)), DIN1.P1 (1), R104.4
GND: C103.1, C104.2, C105.2, D30.8 (GND), D30.22 (GND), D31.14 (VSS), D31.20 (!CE), DIN1.G1 (GND), DIN1.G2 (GND), DIN1.G3 (GND), DIN1.P3 (3), ISP.6; also elsewhere on the board
unnamed: C103.2, D30.21 (AREF)
unnamed: D30.1 (PC6(/RESET)), ISP.5, R104.6
unnamed: D30.26 (PC3(ADC3)), VD101.C

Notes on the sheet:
PS/2 Kbd Adapter, ROM Disk

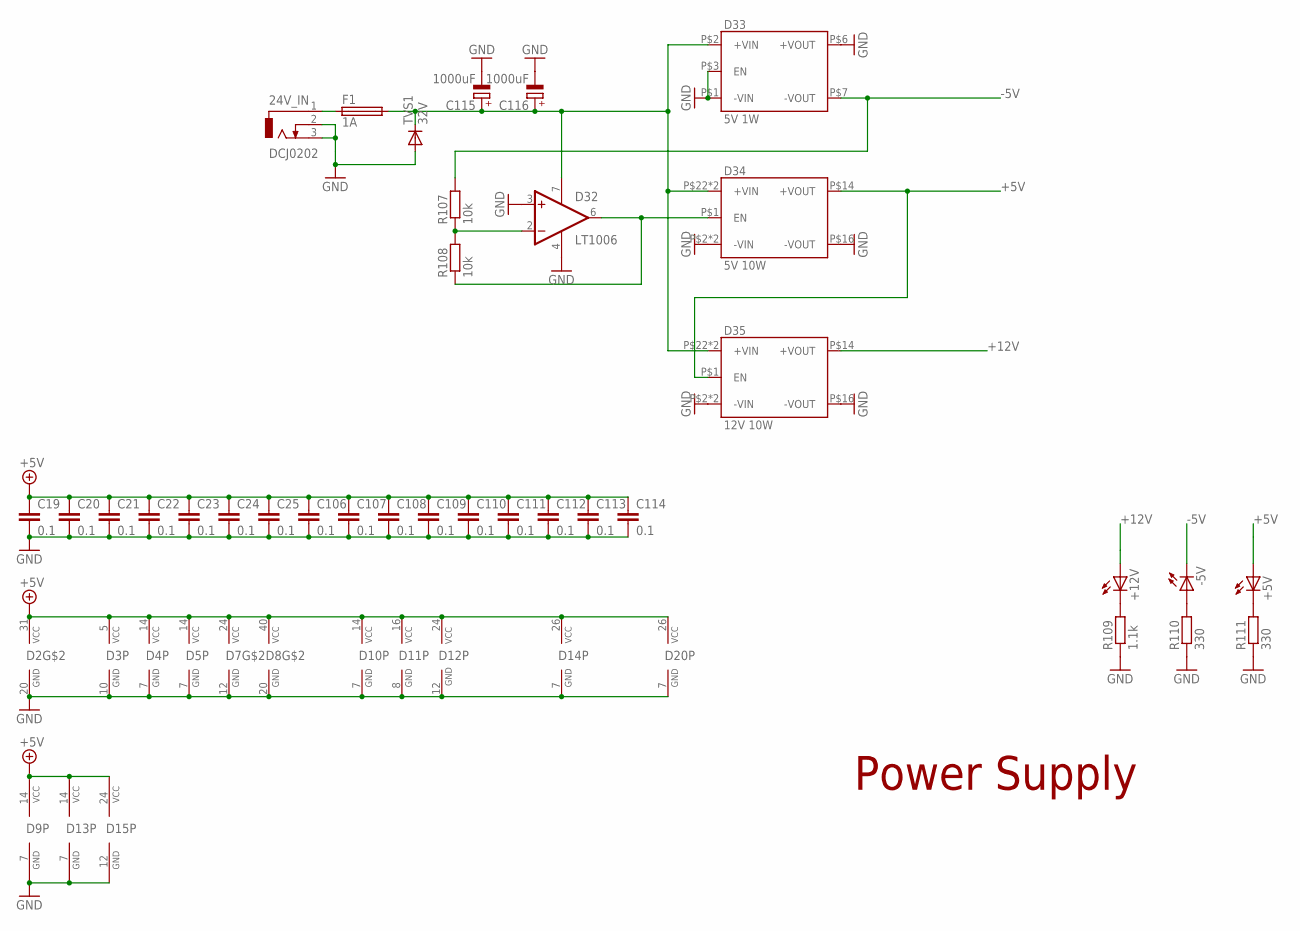
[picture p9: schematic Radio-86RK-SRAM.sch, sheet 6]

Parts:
24V_IN: DCJ0202
+5V, +12V: LED3MM
-5V: LED3MM
C19, C20, C21, C22, C23, C24, C25, C106, C107, C108, C109, C110, C111, C112, C113, C114: 0.1; C050-024X044
C115: 1000uF; E5-13
C116: 1000uF; E7,5-18
D2: i8257; DIL40
D3: 74LS92N; DIL14
D4: 74S08N; DIL14
D5: 74LS86N; DIL14
D7: 8212; DIL24-6
D8: 8275; DIL40
D9: 7404N; DIL14
D10: 74LS00N; DIL14
D11: 74LS138N; DIL16
D12: AT28C16; DIL24
D13: 74S74N; DIL14
D14, D20: 8255A; DIL40
D15: 74198N; DIL24-6
D32: LT1006; DIL08
D33: 5V 1W; DC/DC_SIP
D34: 5V 10W; DC/DC_24PIN
D35: 12V 10W; DC/DC_24PIN
F1: 1A; TE5
R107, R108: 10k; 0207/10
R109: 1.1k; 0207/10
R110, R111: 330; 0207/10
TVS1: 32V; DO41-10

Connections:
+5V: +5V.A, C19.1, C20.1, C21.1, C22.1, C23.1, C24.1, C25.1, C106.1, C107.1, C108.1, C109.1, C110.1, C111.1, C112.1, C113.1, C114.1, D2.31 (VCC), D3.5 (VCC), D4.14 (VCC), D5.14 (VCC), D7.24 (VCC), D8.40 (VCC), D9.14 (VCC), D10.14 (VCC), D11.16 (VCC), D12.24 (VCC), D13.14 (VCC), D14.26 (VCC), D15.24 (VCC), D20.26 (VCC), D34.P$14 (+VOUT), D35.P$1 (EN); also elsewhere on the board
+12V: +12V.A, D35.P$14 (+VOUT); also elsewhere on the board
-5V: -5V.K (C), D33.P$7 (-VOUT), R107.2; also elsewhere on the board
GND: 24V_IN.2, 24V_IN.3, C19.2, C20.2, C21.2, C22.2, C23.2, C24.2, C25.2, C106.2, C107.2, C108.2, C109.2, C110.2, C111.2, C112.2, C113.2, C114.2, C115.-, C116.-, D2.20 (GND), D3.10 (GND), D4.7 (GND), D5.7 (GND), D7.12 (GND), D8.20 (GND), D9.7 (GND), D10.7 (GND), D11.8 (GND), D12.12 (GND), D13.7 (GND), D14.7 (GND), D15.12 (GND), D20.7 (GND), D32.3 (+IN), D32.4 (V-), D33.P$1 (-VIN), D33.P$3 (EN), D33.P$6 (+VOUT), D34.P$2 (-VIN), D34.P$3 (-VIN), D34.P$16 (-VOUT), D35.P$2 (-VIN), D35.P$3 (-VIN), D35.P$16 (-VOUT), R109.1, R110.1, R111.1, TVS1.A; also elsewhere on the board
unnamed: +5V.K (C), R111.2
unnamed: +12V.K (C), R109.2
unnamed: -5V.A, R110.2
unnamed: 24V_IN.1, F1.1
unnamed: C115.+, C116.+, D32.7 (V+), D33.P$2 (+VIN), D34.P$22 (+VIN), D34.P$23 (+VIN), D35.P$22 (+VIN), D35.P$23 (+VIN), F1.2, TVS1.C
unnamed: D32.6 (OUT), D34.P$1 (EN), R108.1
unnamed: D32.2 (-IN), R107.1, R108.2

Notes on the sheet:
Power Supply

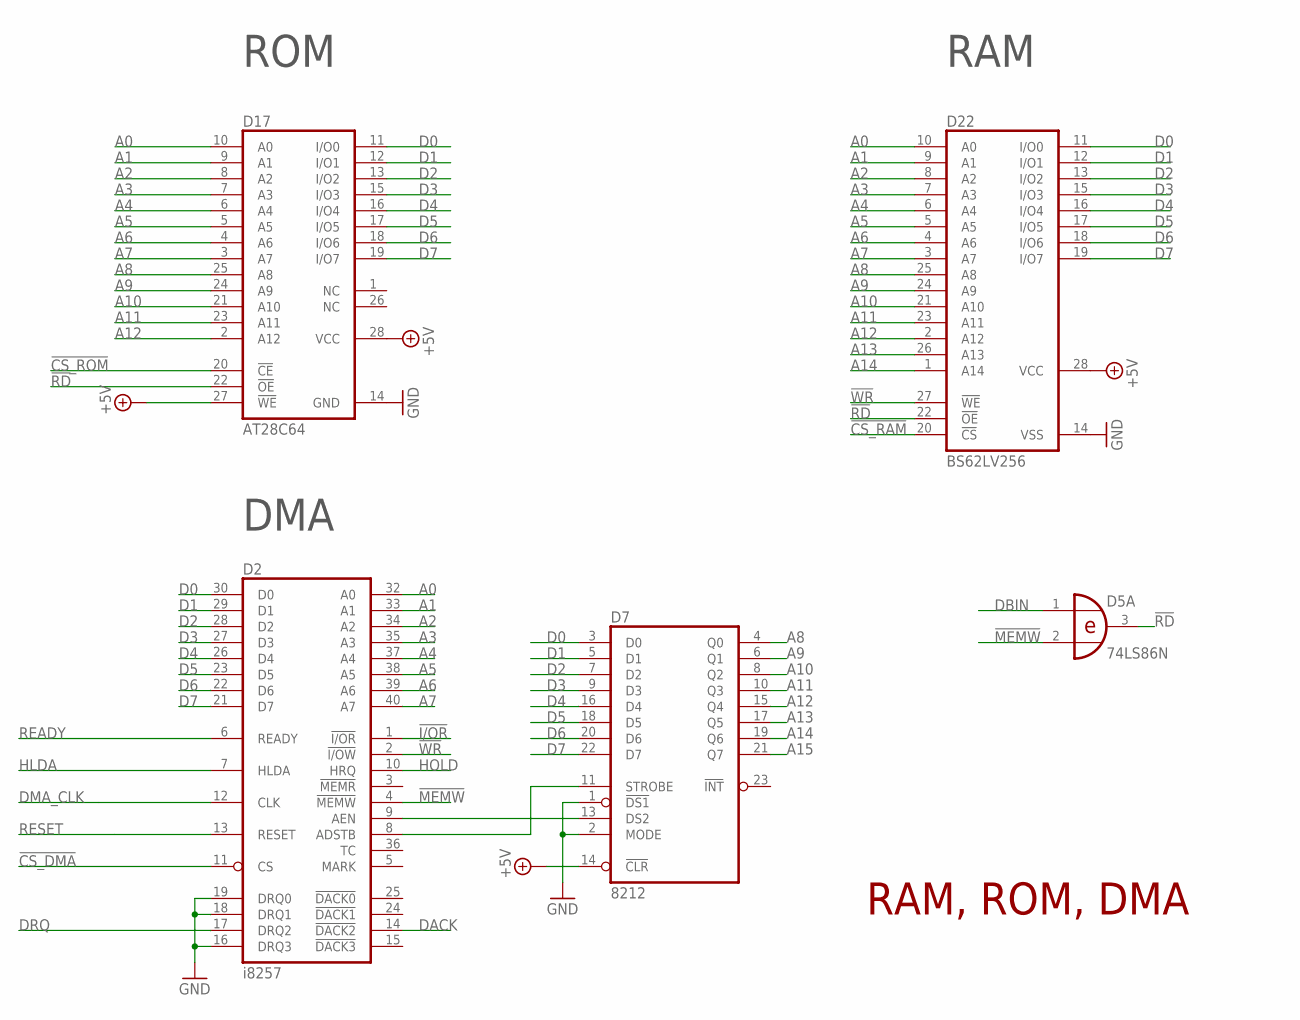
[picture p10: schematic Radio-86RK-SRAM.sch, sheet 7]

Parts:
D2: i8257; DIL40
D5: 74LS86N; DIL14
D7: 8212; DIL24-6
D17: AT28C64; DIL28-6
D22: BS62LV256; DIL28-6

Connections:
!CS_DMA: D2.11 (CS); also elsewhere on the board
!CS_RAM: D22.20 (!CS); also elsewhere on the board
!CS_ROM: D17.20 (!CE); also elsewhere on the board
!I/OR: D2.1 (!I/OR); also elsewhere on the board
!MEMW: D2.4 (!MEMW), D5.2 (I1); also elsewhere on the board
!RD: D5.3 (O), D17.22 (!OE), D22.22 (!OE); also elsewhere on the board
!WR: D2.2 (!I/OW), D22.27 (!WE); also elsewhere on the board
+5V: D7.14 (!CLR), D17.27 (!WE), D17.28 (VCC), D22.28 (VCC); also elsewhere on the board
A0: D2.32 (A0), D17.10 (A0), D22.10 (A0); also elsewhere on the board
A1: D2.33 (A1), D17.9 (A1), D22.9 (A1); also elsewhere on the board
A2: D2.34 (A2), D17.8 (A2), D22.8 (A2); also elsewhere on the board
A3: D2.35 (A3), D17.7 (A3), D22.7 (A3); also elsewhere on the board
A4: D2.37 (A4), D17.6 (A4), D22.6 (A4); also elsewhere on the board
A5: D2.38 (A5), D17.5 (A5), D22.5 (A5); also elsewhere on the board
A6: D2.39 (A6), D17.4 (A6), D22.4 (A6); also elsewhere on the board
A7: D2.40 (A7), D17.3 (A7), D22.3 (A7); also elsewhere on the board
A8: D7.4 (Q0), D17.25 (A8), D22.25 (A8); also elsewhere on the board
A9: D7.6 (Q1), D17.24 (A9), D22.24 (A9); also elsewhere on the board
A10: D7.8 (Q2), D17.21 (A10), D22.21 (A10); also elsewhere on the board
A11: D7.10 (Q3), D17.23 (A11), D22.23 (A11); also elsewhere on the board
A12: D7.15 (Q4), D17.2 (A12), D22.2 (A12); also elsewhere on the board
A13: D7.17 (Q5), D22.26 (A13); also elsewhere on the board
A14: D7.19 (Q6), D22.1 (A14); also elsewhere on the board
A15: D7.21 (Q7); also elsewhere on the board
D0: D2.30 (D0), D7.3 (D0), D17.11 (I/O0), D22.11 (I/O0); also elsewhere on the board
D1: D2.29 (D1), D7.5 (D1), D17.12 (I/O1), D22.12 (I/O1); also elsewhere on the board
D2: D2.28 (D2), D7.7 (D2), D17.13 (I/O2), D22.13 (I/O2); also elsewhere on the board
D3: D2.27 (D3), D7.9 (D3), D17.15 (I/O3), D22.15 (I/O3); also elsewhere on the board
D4: D2.26 (D4), D7.16 (D4), D17.16 (I/O4), D22.16 (I/O4); also elsewhere on the board
D5: D2.23 (D5), D7.18 (D5), D17.17 (I/O5), D22.17 (I/O5); also elsewhere on the board
D6: D2.22 (D6), D7.20 (D6), D17.18 (I/O6), D22.18 (I/O6); also elsewhere on the board
D7: D2.21 (D7), D7.22 (D7), D17.19 (I/O7), D22.19 (I/O7); also elsewhere on the board
DACK: D2.14 (!DACK2); also elsewhere on the board
DBIN: D5.1 (I0); also elsewhere on the board
DMA_CLK: D2.12 (CLK); also elsewhere on the board
DRQ: D2.17 (DRQ2); also elsewhere on the board
GND: D2.16 (DRQ3), D2.18 (DRQ1), D2.19 (DRQ0), D7.1 (!DS1), D7.2 (MODE), D17.14 (GND), D22.14 (VSS); also elsewhere on the board
HLDA: D2.7 (HLDA); also elsewhere on the board
HOLD: D2.10 (HRQ); also elsewhere on the board
unnamed: D2.8 (ADSTB), D7.11 (STROBE)
unnamed: D2.9 (AEN), D7.13 (DS2)
READY: D2.6 (READY); also elsewhere on the board
RESET: D2.13 (RESET); also elsewhere on the board

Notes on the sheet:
RAM, ROM, DMA
ROM
RAM
DMA

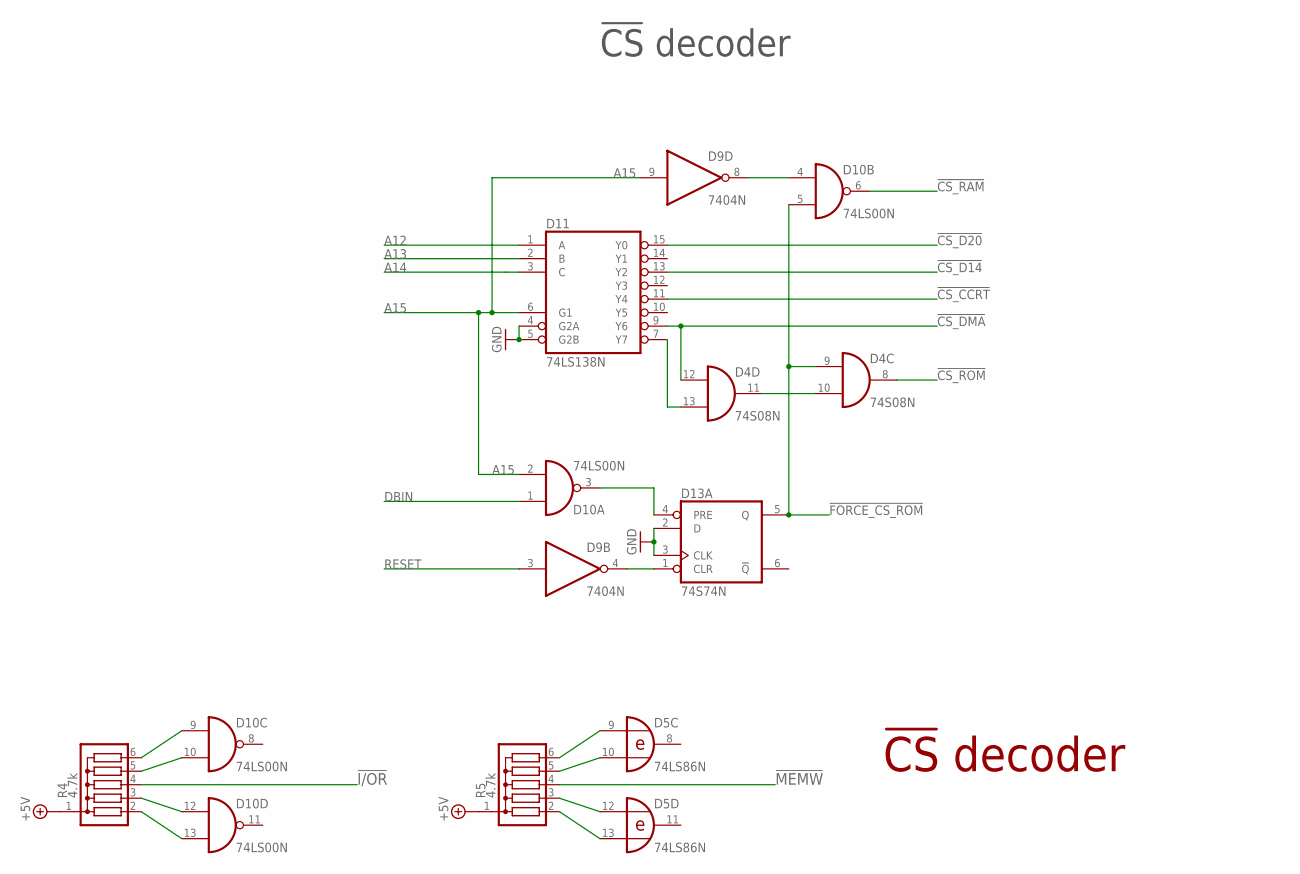
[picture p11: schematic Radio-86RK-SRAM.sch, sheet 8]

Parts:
D4: 74S08N; DIL14
D5: 74LS86N; DIL14
D9: 7404N; DIL14
D10: 74LS00N; DIL14
D11: 74LS138N; DIL16
D13: 74S74N; DIL14
R4, R5: 4.7k; SIL6

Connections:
!CS_CCRT: D11.11 (Y4); also elsewhere on the board
!CS_D14: D11.13 (Y2); also elsewhere on the board
!CS_D20: D11.15 (Y0); also elsewhere on the board
!CS_DMA: D4.12 (I0), D11.9 (Y6); also elsewhere on the board
!CS_F000: D4.13 (I1), D11.7 (Y7)
!CS_RAM: D10.6 (O); also elsewhere on the board
!CS_ROM: D4.8 (O); also elsewhere on the board
!FORCE_CS_ROM: D4.9 (I0), D10.5 (I1), D13.5 (Q)
!I/OR: R4.4; also elsewhere on the board
!MEMW: R5.4; also elsewhere on the board
+5V: R4.1, R5.1; also elsewhere on the board
A12: D11.1 (A); also elsewhere on the board
A13: D11.2 (B); also elsewhere on the board
A14: D11.3 (C); also elsewhere on the board
A15: D9.9 (I), D10.2 (I1), D11.6 (G1); also elsewhere on the board
DBIN: D10.1 (I0); also elsewhere on the board
GND: D11.4 (G2A), D11.5 (G2B), D13.2 (D), D13.3 (CLK); also elsewhere on the board
unnamed: D10.3 (O), D13.4 (PRE)
unnamed: D9.4 (O), D13.1 (CLR)
unnamed: D4.10 (I1), D4.11 (O)
unnamed: D9.8 (O), D10.4 (I0)
unnamed: D10.13 (I1), R4.2
unnamed: D10.12 (I0), R4.3
unnamed: D10.10 (I1), R4.5
unnamed: D10.9 (I0), R4.6
unnamed: D5.13 (I1), R5.2
unnamed: D5.12 (I0), R5.3
unnamed: D5.10 (I1), R5.5
unnamed: D5.9 (I0), R5.6
RESET: D9.3 (I); also elsewhere on the board

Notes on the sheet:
!CS! decoder

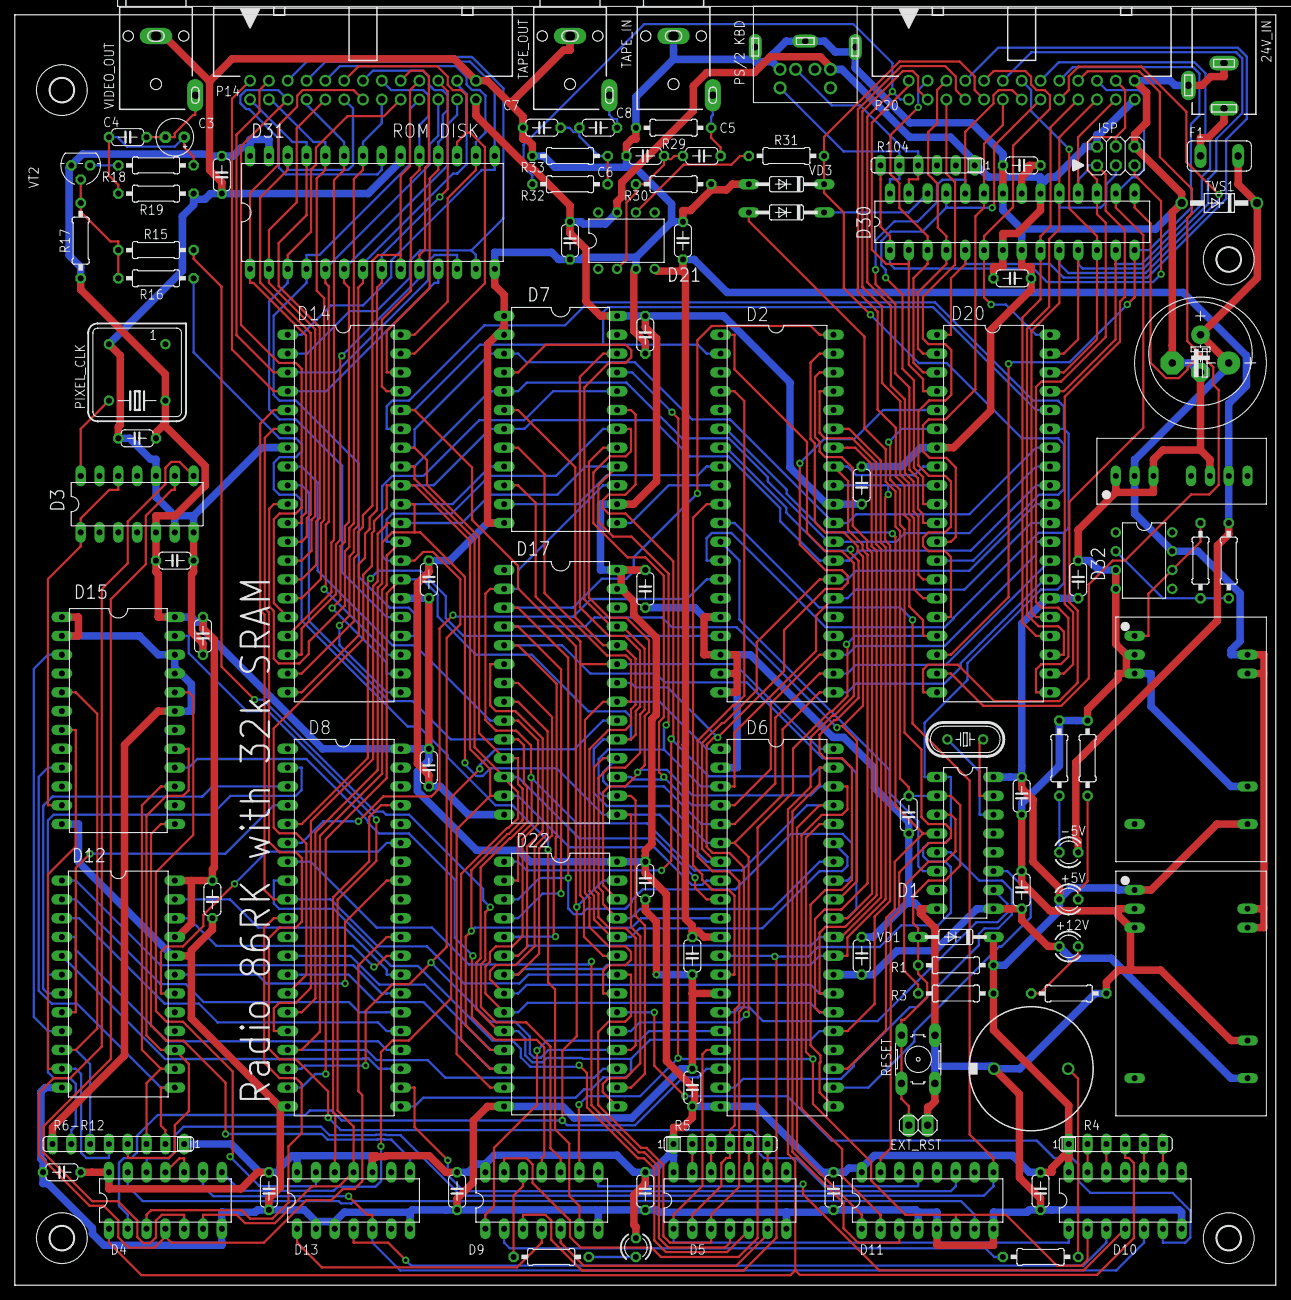
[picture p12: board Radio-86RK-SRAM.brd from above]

Board: 2 copper layers, 170.2 x 171.4 mm, 111 parts (0 on the bottom side), 177 nets.

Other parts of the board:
C: 3,2
F: 3,2
H: 3,2
J: 3,2
